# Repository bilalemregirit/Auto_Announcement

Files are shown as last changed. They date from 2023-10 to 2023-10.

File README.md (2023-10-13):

# OPEN SOURCE - WORK IN PROGRESS
Youtube Video of the Project: https://www.youtube.com/watch?v=9ex4jSiTSgA&t=38s

THE LATEST VERSION OF THE PROJECT
Ekran görüntüsü 2023-10-05 132101

# HOW IT WORKS

This is a project that automizes the announcements of the public transportations with the GPS coordinates. And This is how it works: First i want to start with the hardware of the device. The device consists of several components. The Dfplayer Mini is used for making announcements. It has an SD card socket to store audio files and provides audio output to the Aux port upon receiving a specific signal. The Arduino Pro Micro stores location data such as longitude and latitude, and it receives GPS signals from the GPS module. When the device is in a specific area, it transmits a signal to the DfPlayer. The GPS module used is the GPS Neo 6m, which includes an antenna. The device also includes a TouchScreen Display called Nextion, which comes with a Windows application for easy customization. Lastly, there is a Dip switch between the microcontroller and the display. This switch allows you to disconnect the display when uploading code to the microcontroller.
beyas

The device contains a common GPS module that provides an estimated location. Firstly, the device waits for user input regarding the intended voyage. Once the user confirms the voyage, the device starts to determine its own location. During this process, the GPS module receives and transmits values from satellites, such as latitude and longitude, to the microcontroller. The microcontroller contains a set of coordinate values that represent specific areas in the work location of the vessel.(you can also reach all the coordinates that i used in bosphorus in the link: rb.gy/ims96)  When the microcontroller detects that the device is within the designated area, it sends a signal to the Df player mini with the specific media file number. The player then starts to play the corresponding media file this is how this device works. Additionally the device is capable of handling announcements that loop at specific intervals. For example, it can play "no smoking" announcements every 30 minutes.

The early beggining of this project includes a tiny OLED screen (SSD1306) with arduino nano and several basic buttons. Older versions: 
Menu Demo (SSD1306): https://www.youtube.com/watch?v=d2qRUfzXhB8&t=34s 
Menu Demo (ST7735) : https://www.youtube.com/watch?v=dHNRrd75gP8

Schematic of the project:
gps_anons

BASİC PCB DESİGN OF CARD:


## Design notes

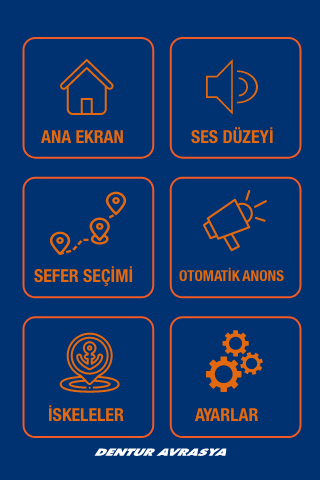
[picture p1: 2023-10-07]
3.5inchnextion_psd/3.5n arkaplan.png

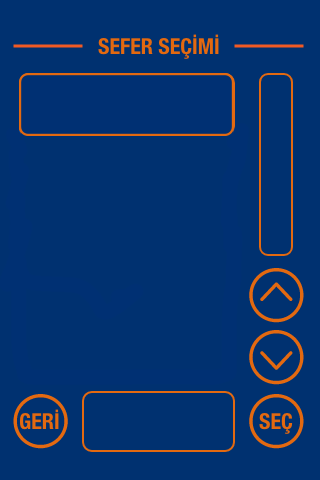
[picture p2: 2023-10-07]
3.5inchnextion_psd/kcuksefetrs.png

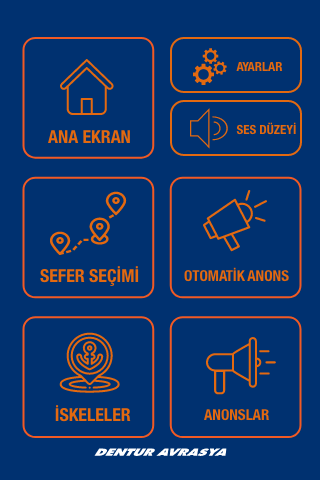
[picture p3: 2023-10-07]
3.5inchnextion_psd/manniiiiiiinnnn.png

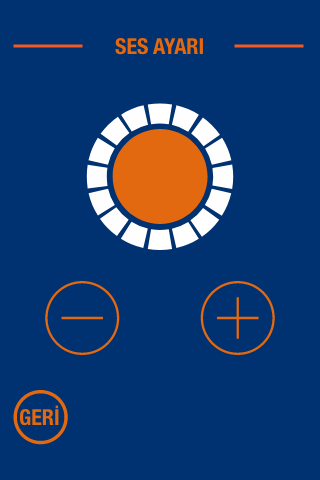
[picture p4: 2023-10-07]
3.5inchnextion_psd/3.5n arkaplan_ses.png

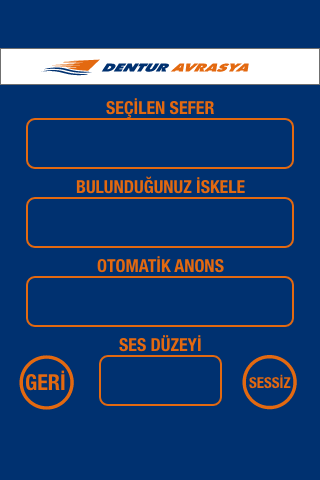
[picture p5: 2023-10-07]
3.5inchnextion_psd/ana ana anan.png

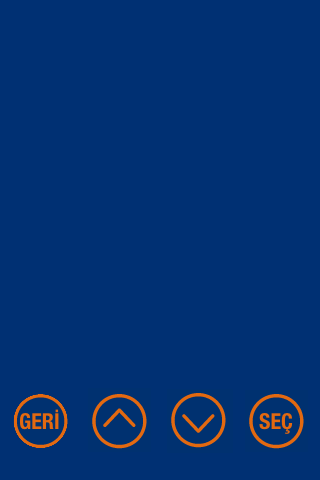
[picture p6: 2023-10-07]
3.5inchnextion_psd/ototototot.png

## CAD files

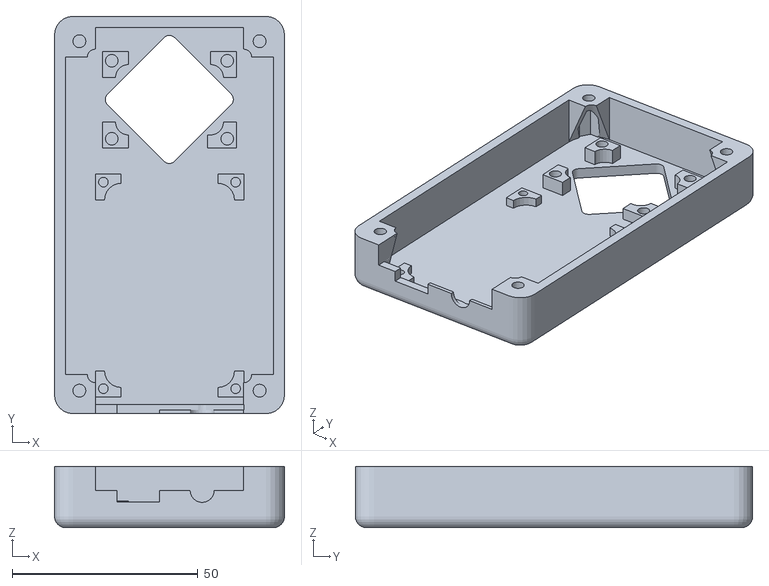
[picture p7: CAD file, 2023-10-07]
3d_drawings/projecAnn_bottom.stl
61.9 x 107.0 x 16.5

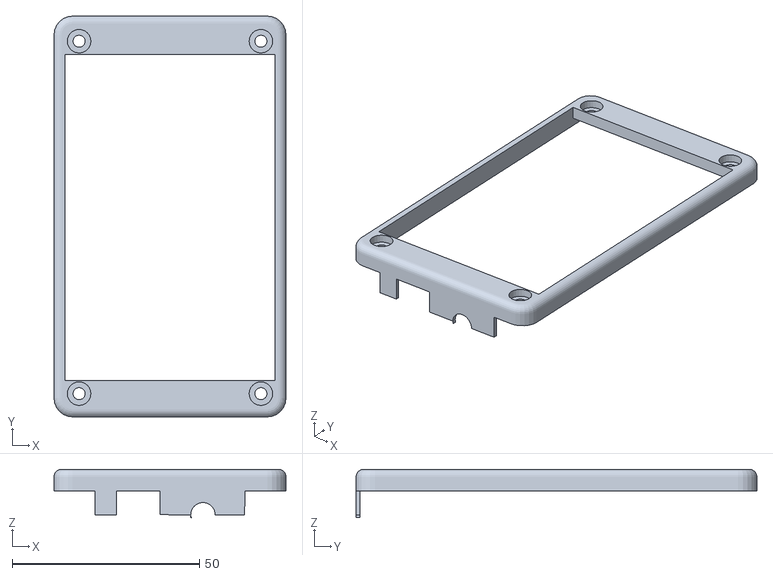
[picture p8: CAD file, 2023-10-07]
3d_drawings/projectAnn_top.stl
61.9 x 107.0 x 12.9

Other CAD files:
3d_drawings/project_announcement.dwg

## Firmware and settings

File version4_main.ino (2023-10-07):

#include "SoftwareSerial.h"
#include "DFRobotDFPlayerMini.h"
#include "TinyGPS.h"

float flat, flon;
float current_loc[2];
uint8_t volume=25;
uint8_t anons_sayac;
uint8_t anons_sayac1;
uint8_t geri_tus=0;
uint8_t sefer_no;
uint8_t ekran_no;
uint8_t vol_no;
uint8_t oto_no1;
uint8_t oto_no2;
uint8_t oto_no3;
uint8_t oto_sw=0;
uint8_t ta_no;
uint8_t tsa_no;
int dak = 60000;
uint8_t iskele_txt_no=0;

String saat;
String dakika;


TinyGPS gps;
SoftwareSerial ssgps(4, 3);
SoftwareSerial mySoftwareSerial(2, 3); // RX, TX
DFRobotDFPlayerMini player;


 byte besiktas_anons=1;
 byte uskudar_anons =2;
 byte kabatas_anons =3;
 byte kadikoy_anons =4;
 byte eminonu_anons =5;
 byte kinaliada_anons =6;
 byte burgazada_anons =7;
 byte heybeliada_anons =8;
 byte buyukada_anons =9;
 byte ahisari_anons=11;
 byte kandilli_anons=12;
 byte kuzguncuk_anons=13;
 byte beylerbeyi_anons=14;
 byte cengelkoy_anons=15;
 byte kucuksu_anons=16;
 byte ortakoy_anons=17;
 byte emirgan_anons= 18;
 byte istinye_anons= 19;
 byte sariyer_anons=20;
 byte kanlica_anons=21;
 byte pasabahce_anons=22;
 byte beykoz_anons=23;
 byte cubuklu_anons=24;
 byte akavagi_anons=25;
 byte arnavutkoy_anons=26;
 byte buyukdere_anons=27;
 byte rkavagi_anons=28;
 byte bebek_anons=29;
 byte bos_anons=30;

  
 byte dolmabahcecamii_bt_anons=31;
 byte dolmabahce_bt_anons=32;
 byte ciragan_bt_anons=33;
 byte feriye_bt_anons=34;
 byte ortakoy_bt_anons=35;
 byte ortakoycamii_bt_anons=36;
 byte bogazicikoprusu_bt_anons=37;
 byte galatasarayadasi_bt_anons=38;
 byte arnavutkoy_bt_anons=39;
 byte akoysirayalilar_bt_anons=40;
 byte akintiburnu_bt_anons=41;
 byte misirkonsolosluk_bt_anons=42;
 byte bebek_bt_anons=43;
 byte rumelihisari_bt_anons=44;
 byte yusufpasakosku_bt_anons=45;
 byte baltalimanihastanesi_bt_anons=46;
 byte emirgan_bt_anons=47;
 byte sakipsabancimuzesi_bt_anons=48;
 byte kanlica_bt_anons=49;
 byte fsmkoprusu_bt_anons=50;
 byte anadoluhisari_bt_anons=51;
 byte kucuksukasri_bt_anons=52;
 byte kandilli_bt_anons=53;
 byte vanikoy_bt_anons=54;
 byte vanikoycamii_bt_anons=55;
 byte kuleliaskerilisesi_bt_anons=56;
 byte sumahan_bt_anons=57;
 byte cengelkoy_bt_anons=58;
 byte beylerbeyi_bt_anons=59;
 byte beylerbeyisarayi_bt_anons=60;
 byte kuzguncuk_bt_anons=61;
 
 float Uskudar_iskele[]= {41.0278426, 29.012778,41.03078, 29.020130};
 float Besiktas_iskele[]={41.03882, 29.00544,41.04266, 29.01091};  
 float Kabatas_iskele[]={41.03291, 28.9926,41.03619, 28.9958};  
 float Kadikoy_iskele[]={40.98950422, 29.014312,40.994346, 29.02416177};
 float Eminonu_iskele[]={41.0164801, 28.9736655,41.020463, 28.98352794}; 
 float Kinaliada_iskele[]={40.90838, 29.05284,40.915, 29.05916};    
 float Burgazada_iskele[]={40.87904, 29.0669,40.88674, 29.07481};    
 float Heybeliada_iskele[]={40.87324, 29.09428,40.88226, 29.1069};    
 float Buyukada_iskele[]={40.87284, 29.1188,40.87894, 29.13074};    
 float Kuzguncuk_iskele[]={41.03409, 29.02859,41.03783, 29.03535};
 float Beylerbeyi_iskele[]={41.04273, 29.04316,41.04607, 29.05026};
 float Cengelkoy_iskele[]={41.0497, 29.04969,41.05224, 29.05351};
 float Kandilli_iskele[]={41.07305, 29.05702,41.0751, 29.06042};
 float Ahisari_iskele[]={41.08226, 29.06475,41.08426, 29.06796};
 float Arnavutkoy_iskele[]={41.06601, 29.04229,41.0676, 29.04454};
 float Bebek_iskele[]={41.07464, 29.04223,41.0777, 29.04616};
 float Emirgan_iskele[]={41.10212, 29.0547,41.10413, 29.05744};
 float Istinye_iskele[]={41.11165, 29.05955,41.11411, 29.06307};
 float Kanlica_iskele[]={41.09931, 29.06432,41.10102, 29.06667};
 float Kucuksu_iskele[]={41.07818, 29.06375,41.08025, 29.06724};
 float Ortakoy_iskele[]={41.04626, 29.02211,41.049, 29.02709};
 float Sariyer_iskele[]={41.16483, 29.056,41.16734, 29.05975}; 
 float Pasabahce_iskele[]={41.11609, 29.08988,41.11878, 29.09513};
 float Beykoz_iskele[]={41.13285, 29.08706,41.13629, 29.09313};
 float Cubuklu_iskele[]={41.10709, 29.07817,41.10937, 29.08202};
 float Akavagi_iskele[]={41.17128, 29.08492,41.1753, 29.092};
 float Rkavagi_iskele[]={41.17958, 29.07215,41.18378, 29.07884};
 float Buyukdere_iskele[]={41.15838, 29.04275,41.16324, 29.05007};
 float dolmabahcecamii_bturu[] ={41.03501, 28.99718,41.03744, 28.99928};
 float dolmabahce_bturu[] ={41.03648, 29.00055,41.03894, 29.00458};
 float ciragan_bturu[] ={41.04036, 29.01353,41.04242, 29.01556};
 float feriye_bturu[] ={41.04156, 29.0173,41.04543, 29.02053};
 float ortakoy_bturu[] ={41.0429, 29.02223,41.04666, 29.02496};
 float ortakoycamii_bturu[] ={41.04417, 29.02566,41.04682, 29.02836};
 float bogazicikoprusu_bturu[] ={41.04591, 29.02985,41.04878, 29.03271};
 float galatasarayadasi_bturu[] ={41.05834, 29.03789,41.06057, 29.04191};
 float arnavutkoy_bturu[] ={41.06102, 29.04083,41.06301, 29.04503};
 float akoysirayalilar_bturu[] ={41.06446, 29.04339,41.06634, 29.04751};
 float akintiburnu_bturu[] ={41.06766, 29.04631,41.06983, 29.04915};
 float misirkonsolosluk_bturu[] ={41.07277, 29.04508,41.0747, 29.04875};
 float bebek_bturu[] ={41.07649, 29.04431,41.07908, 29.05085};
 float rumelihisari_bturu[] ={41.08268, 29.05594,41.08476, 29.05979};
 float yusufpasakosku_bturu[] ={41.08826, 29.05719,41.09003, 29.05992};
 float baltalimanihastanesi_bturu[] ={41.09462, 29.05383,41.09626, 29.05802};
 float emirgan_bturu[] ={41.09768, 29.05452,41.0989, 29.05795};
 float sakipsabancimuzesi_bturu[] ={41.10014, 29.05477,41.10122, 29.05789};
 float kanlica_bturu[] ={41.09937, 29.06297,41.10105, 29.06596};
 float fsmkoprusu_bturu[] ={41.09182, 29.0626,41.09412, 29.06646};
 float anadoluhisari_bturu[] ={41.08431, 29.06452,41.08589, 29.0674};
 float kucuksukasri_bturu[] ={41.07972, 29.06239,41.08144, 29.06596};
 float kandilli_bturu[] ={41.07463, 29.05766,41.07638, 29.06094};
 float vanikoy_bturu[] ={41.06831, 29.05337,41.06973, 29.05741};
 float vanikoycamii_bturu[] ={41.06456, 29.05351,41.06635, 29.05661};
 float kuleliaskerilisesi_bturu[] ={41.05843, 29.04998,41.06055, 29.05334};
 float sumahan_bturu[] ={41.05549, 29.04961,41.05665, 29.05294};
 float cengelkoy_bturu[] ={41.05047, 29.04821,41.05242, 29.05193};
 float beylerbeyi_bturu[] ={41.04672, 29.04516,41.04819, 29.04844};
 float beylerbeyisarayi_bturu[] ={41.04233, 29.03664,41.04439, 29.04049};
 float kuzguncuk_bturu[] ={41.038, 29.02937,41.04054, 29.03351};
 

/* 
 float Kanlica_iskele[]={,};
 float Kanlica_iskele[]={,};
 */
 
 
 

 
void setup() 
{
  Serial.begin(9600);
  mySoftwareSerial.begin(9600);

  if(!player.begin(mySoftwareSerial)) 
   {  
    Serial.println(F("Unable to begin:"));
    Serial.println(F("1.Please recheck the connection!"));
    Serial.println(F("2.Please insert the SD card!"));   
   }
   Serial.println(F("DFPlayer Mini online."));
   delay(0);
   
   ssgps.begin(9600);
   
} 

  static void smartdelay(unsigned long ms)
  {
    unsigned long start = millis();
    do  
    {while (ssgps.available())
     gps.encode(ssgps.read());}
     while (millis() - start < ms);
  }

    int anons_yap(int x)
  {   
     static unsigned long timer1 = millis();
     if (millis() - timer1 > 15500) 
     {
     timer1 = millis();    
     player.volume(volume); 
     player.play(x);
     anons_sayac ++; 
     anons_sayac1++; 
     }
  }

  int oto_anons_yap(long y,long x)
   {
     static unsigned long timer1 = millis();
     if (millis() - timer1 > y) 
     {
     timer1 = millis();
     player.volume(volume); 
     player.play(x);
     }
     
   }
    float InorOut(float x[],float y[])
   { 
      if(x[0]< y[0] &&
         x[2]> y[0] &&
         x[1]< y[1] &&
         x[3]> y[1] ) 
      {return true;}
      else
      {return false;}    
   }

   int sefer_secimi(int sefer_nu)
  { 
    /*
    if(sefer_nu ==0) // SEFER DENEME
    {
         if(InorOut(Bizim_ev_konum,current_loc)==true)
         {if(anons_sayac < 3)
         {anons_yap(1);
         }}              
         else
         {anons_sayac = 0;} 
    }
    */
    if(sefer_nu ==1) // KADIKÖY BESİKTAS 
    {
         if(InorOut(Kadikoy_iskele,current_loc)==true)
         {
          iskele_txt_no=4;
          if(anons_sayac < 2)
         {anons_yap(4);
         
         }}            
         else if(InorOut(Besiktas_iskele,current_loc)==true)
         {
          iskele_txt_no=2;
          if(anons_sayac < 2)
         {anons_yap(1);
         }}  
         else
         {iskele_txt_no=0;
          anons_sayac = 0;} 
    }
    
    if(sefer_nu ==2) // ÜSKÜDAR BESİKTAS 
    {
         if(InorOut(Uskudar_iskele,current_loc)==true)
         {
          iskele_txt_no=1;
          if(anons_sayac < 2)
         {anons_yap(2);
         }}            
         else if(InorOut(Besiktas_iskele,current_loc)==true)
         {
          iskele_txt_no=2;
          if(anons_sayac < 2)
         {anons_yap(1);}}      
         else
         {iskele_txt_no=0;
          anons_sayac = 0;}     
     }  

     if(sefer_nu ==3) // ÜSKÜDAR KABATAS
    {
         if(InorOut(Uskudar_iskele,current_loc)==true)
         {iskele_txt_no=1;
          if(anons_sayac < 2)
         {anons_yap(2);
         }}            
         else if(InorOut(Kabatas_iskele,current_loc)==true)
         {iskele_txt_no=3;
          if(anons_sayac < 2)
         {anons_yap(3);}}      
         else
         {iskele_txt_no=0;
          anons_sayac = 0;}     
     }  

     if(sefer_nu ==4) // KADIKÖY KABATAŞ
    {
         if(InorOut(Kadikoy_iskele,current_loc)==true)
         {iskele_txt_no=4;
          if(anons_sayac < 2)
         {anons_yap(4);
         }}            
         else if(InorOut(Kabatas_iskele,current_loc)==true)
         {iskele_txt_no=3;
          if(anons_sayac < 2)
         {anons_yap(3);}}      
         else
         {iskele_txt_no=0;
          anons_sayac = 0;}     
     }
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
void loop() {

  //--------------------------------ANONS_AYARLARI-----------------------------------
   
  
   sefer_secimi(sefer_no);
 
 if(oto_sw==1)
 {
   switch (oto_no1) 
  {
   case 1: 
      oto_anons_yap(oto_no1*60000,10);
      break; 
   
   case 2: 
      oto_anons_yap(oto_no1*60000,10);
      break;  
   
   case 3: 
      oto_anons_yap(oto_no1*60000,10);
      break; 
      
   case 4: 
      oto_anons_yap(oto_no1*60000,10);
      break; 

   case 5: 
      oto_anons_yap(oto_no1*60000,10);
      break; 

   case 10: 
      oto_anons_yap(oto_no1*60000,10);
      break; 

   case 15: 
      oto_anons_yap(oto_no1*60000,10);
      break; 

   case 20: 
      oto_anons_yap(oto_no1*60000,10);
      break; 
      
   case 25: 
      oto_anons_yap(oto_no1*60000,10);
      break; 
      
   case 30: 
      oto_anons_yap(oto_no1*60000,10);
      break; 
   
   case 45: 
      oto_anons_yap(oto_no1*60000,10);
      break; 
  
   case 60: 
      oto_anons_yap(oto_no1*60000,10);
      break; 
  }
 }
 else if(oto_sw==0)
 {}
  //--------------------------------ANONS_AYARLARI-----------------------------------
   
  //--------------------------------GPS-----------------------------------
    int year;
    byte month, day, hour, minute, second, hundredths;
    unsigned long age2;
    gps.crack_datetime(&year, &month, &day, &hour, &minute, &second, &hundredths, &age2);
    int bagli_uydu = gps.satellites();
    
    unsigned long age;
    gps.f_get_position(&flat, &flon, &age);
   
    current_loc[0] = flat, 6;
    current_loc[1] = flon, 6;
   /*
    current_loc[0] = 41.03779;
    current_loc[1] = 29.00259;
    */ 
    smartdelay(100);
    
    int deger1=flat;
    int deger2=flon;
 
    
   
   //--------------------------------GPS-----------------------------------
   
   //--------------------------------NEXTİON_SERIAL-----------------------------------
  if(Serial.available())
  { 
    String data = "";
    while(Serial.available())
    {
      data += char(Serial.read());
    }
   
    if(data.substring(0,8)=="B.BPAGE0")
    {
     ekran_no=0;  
    }
    if(data.substring(0,8)=="B.BPAGE1")
    {
      Serial.println(iskele_txt_no);
     ekran_no=1;
          if(data.substring(7,9)=="12")
          {  
          ekran_no=12;  
          Serial.print("f4.val=");
          Serial.print(iskele_txt_no);
          Serial.write(0xff);
          Serial.write(0xff);
          Serial.write(0xff);
          }
          if(data.substring(8,10)=="SS")
          {    
          player.volume(volume); 
          player.play(30);
          }
    }
    if(data.substring(0,8)=="B.BPAGE2")
    {
     ekran_no=2;
     vol_no = data.substring(8,10).toInt();
     
    }
    if(data.substring(0,8)=="B.BPAGE3")
    {
     ekran_no=3;
    // Serial.println(data);
    // Serial.println(data.substring(8,10).toInt());
     sefer_no = data.substring(8,10).toInt();
     
     Serial.print("n53.val=");
     Serial.print(sefer_no);
     Serial.write(0xff);
     Serial.write(0xff);
     Serial.write(0xff);

    }
    if(data.substring(0,8)=="B.BPAGE4")
    {
         ekran_no=4;
         //Serial.println(oto_no1);
         if(data.substring(10,11)=="M")
         { 
         oto_sw=1;
         oto_no1 = data.substring(8,10).toInt();
         oto_no2 = data.substring(11,13).toInt();  
         //Serial.println(oto_no1*60000);   
         }
         if(data.substring(10,11)=="W")
         {
         oto_no2 = data.substring(8,10).toInt();
         oto_no3 = data.substring(11,13).toInt();
         oto_no1 = data.substring(14,16).toInt();
         if(saat==oto_no2 && dakika==oto_no3)
         {
         oto_sw=1;
         }    
         }        
    }
         if(data.substring(0,8)=="B.BPAGE5")
     { 
         ekran_no=5;
         
         ta_no=data.substring(9,11).toInt();
         /*
         Serial.print(anons_sayac1);
         Serial.print("   ");
         Serial.println(ta_no);
         */
         static unsigned long timer2 = millis();
         if (millis() - timer2 > 10000) 
         {
         timer2 = millis();    
         anons_sayac1=0;
         }   
         if(ta_no>0 && ta_no<30)
         {if(anons_sayac1 < 1)
         {player.volume(volume); 
          player.play(ta_no);
          anons_sayac1++;}
         else if(anons_sayac1==1)
         {ta_no = 0;} }
             
        
     }
    if(data.substring(0,8)=="B.BPAGE7")
     { 
             ekran_no=7;
             tsa_no=data.substring(8,10).toInt();
             //Serial.println(tsa_no);

             
              static unsigned long timer3 = millis();
              if (millis() - timer3 > 15000) 
              {
              timer3 = millis();    
              anons_sayac1=0;
              } 
                
              if(tsa_no>0 && tsa_no<30)
              {if(anons_sayac1 < 1)
              {player.volume(volume); 
              player.play(tsa_no);
              anons_sayac1++;}
              else if(anons_sayac1==1)
              {ta_no = 0;} }   

         
     }
   
      if(data.substring(0,8)=="B.BPAGE6")
    {
     ekran_no=6;
    }
    }

     /*
         static unsigned long timer4 = millis();     //ANA MENU
         if (millis() - timer4 > 60000) 
         {
         timer4 = millis();    
         Serial.print("page ");
         Serial.print("page1");
         Serial.write(0xff);
         Serial.write(0xff);
         Serial.write(0xff);
         }   
     */
  
  uint8_t gps_logo;
  uint8_t saat_durum;
  long saat0_renk;
  long saat1_renk;
  String saat_text;
  saat= String(hour+3);
  if(minute<=9)
  {dakika= "0"+String(minute);}
  else 
  {dakika= String(minute);}
  saat_text= saat+ dakika;

if(ekran_no==4)
   {
  Serial.print("n4.val=");
  Serial.print(saat);
  Serial.write(0xff);
  Serial.write(0xff);
  Serial.write(0xff);
  
  Serial.print("n5.val=");
  Serial.print(dakika);
  Serial.write(0xff);
  Serial.write(0xff);
  Serial.write(0xff);

  }
  
 
  if(
     ekran_no==1||
     ekran_no==2||
     ekran_no==4||
     ekran_no==6||
     ekran_no==7)
  {
 if(flat==1000 && flon==1000 )
  {
  Serial.print("t12.pco=");
  Serial.print(59392);
  Serial.write(0xff);
  Serial.write(0xff);
  Serial.write(0xff);
  
  Serial.print("x12.pco=");
  Serial.print(397);
  Serial.write(0xff);
  Serial.write(0xff);
  Serial.write(0xff);
  }
  else
  {
  Serial.print("t12.pco=");
  Serial.print(397);
  Serial.write(0xff);
  Serial.write(0xff);
  Serial.write(0xff);
  
  Serial.print("x12.pco=");
  Serial.print(64512);
  Serial.write(0xff);
  Serial.write(0xff);
  Serial.write(0xff);
  
  Serial.print("x12.val=");
  Serial.print(saat_text.toInt());
  Serial.write(0xff);
  Serial.write(0xff);
  Serial.write(0xff);
  }  
  }
  else
  {}
 

 if(ekran_no==6)
   {
  Serial.print("x0.val=");
  Serial.print(deger1);
  Serial.write(0xff);
  Serial.write(0xff);
  Serial.write(0xff);
  
  Serial.print("x1.val=");
  Serial.print(deger2);
  Serial.write(0xff);
  Serial.write(0xff);
  Serial.write(0xff);

  Serial.print("x2.val=");
  Serial.print(sefer_no);
  Serial.write(0xff);
  Serial.write(0xff);
  Serial.write(0xff);

  Serial.print("x3.val=");
  Serial.print(oto_no1);
  Serial.write(0xff);
  Serial.write(0xff);
  Serial.write(0xff);

  Serial.print("x4.val=");
  Serial.print(vol_no);
  Serial.write(0xff);
  Serial.write(0xff);
  Serial.write(0xff);
  
  Serial.print("x5.val=");
  Serial.print(iskele_txt_no);
  Serial.write(0xff);
  Serial.write(0xff);
  Serial.write(0xff);
  }
  
  if(ekran_no==1)
   {
    
   

    Serial.print("n0.val=");
    Serial.print(iskele_txt_no);
    Serial.write(0xff);
    Serial.write(0xff);
    Serial.write(0xff);
   
    Serial.print("n2.val=");
    Serial.print(sefer_no);
    Serial.write(0xff);
    Serial.write(0xff);
    Serial.write(0xff);
    
    }
    }
   //--------------------------------NEXTİON_SERIAL-----------------------------------
  
  
  
